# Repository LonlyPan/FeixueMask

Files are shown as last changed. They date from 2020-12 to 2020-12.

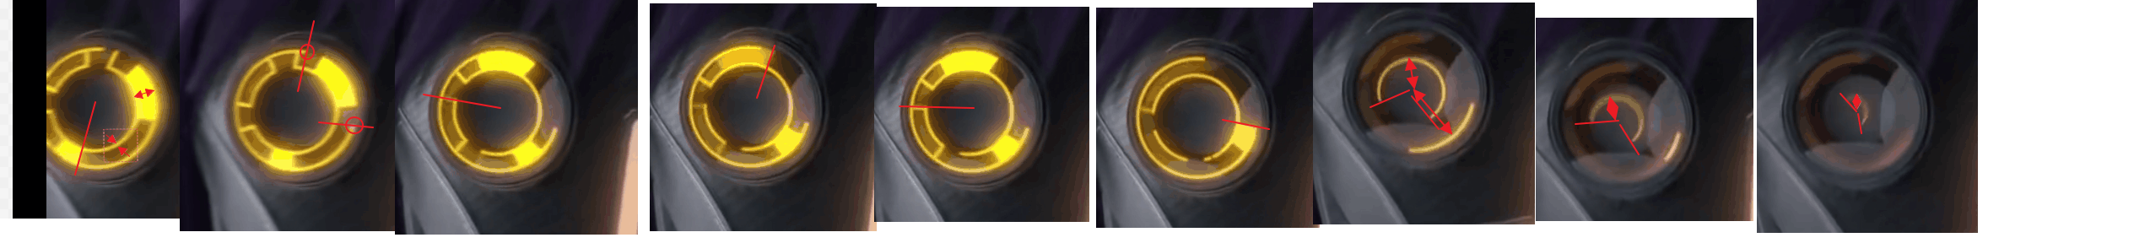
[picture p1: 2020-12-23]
04_others/飞雪显示界面/po57pm6ot55y8552bLeinkuW6pi5wbmc=.png

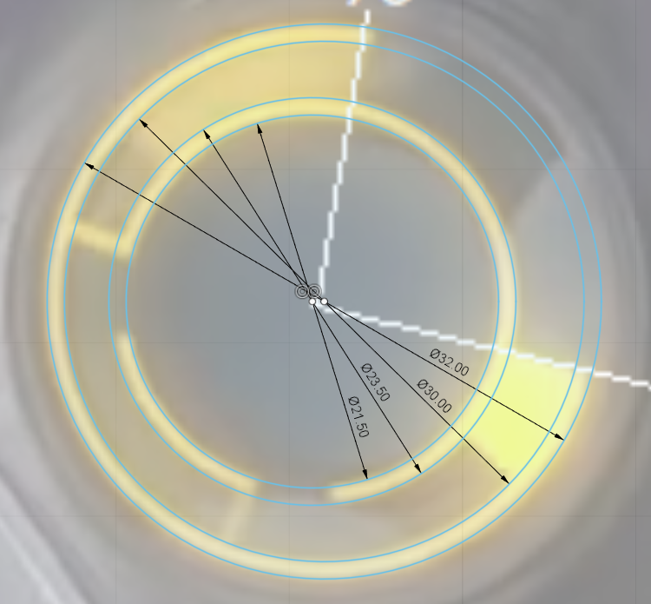
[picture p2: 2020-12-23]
04_others/飞雪显示界面/飞雪眼睛-线条宽度.png

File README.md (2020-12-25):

# 飞雪面具控制板源码




- **[English](/README_EN.md)**

飞雪面具控制板是[飞雪面具](https://www.bilibili.com/video/BV1Dy4y1i72c)的配套产品。

enter description here

## 如何找到文件

### 00_Priority README
该目录下存放了该控制板项目的全部**技术文档**，对该项目的程序源码、PCB设计都有详细说明，请首先阅读。
>文档目前尚未编写完成
>
### 01_Firmware
该目录下存放了 **软件/程序** 相关的全部源文件

### 02_Electronics
该目录下存放了 **电路/PCB** 相关的全部源文件

### 04_others
即不属于 软件/程序 也不属于 电路/PCB，但和本项目相关的其它文件

###  README.txt
每个文件夹下都有该文档，请**首先阅读**。这包含有其所处文件夹的阅读索引及一些重要说明。

## FeixueMask 1.0
FeixueMask 1.0 是该固件的初始版本，已经经过测试，可正常使用。

在[发布页面](https://github.com/LonlyPan/FeixueMask/releases)下载早期版本的FeixueMask固件。
>目前还未发布任何历史版本

## 支持

为了获得最佳的配置和故障排除帮助，请使用以下资源：
- 哔哩哔哩：[猩造](https://space.bilibili.com/16614468/)  
- 聊天催更Q群：779627778

## 许可协议

FeixueMask 是遵循 [GPL license](/LICENSE) 协议发行的，因为我们相信开放式开发。 GPL附带了权利和义务。 无论您使用 FeixueMask 固件作为开源产品还是封闭源产品的驱动程序，都必须保持 FeixueMask 开放，并且必须根据要求向最终用户提供兼容的 FeixueMask 源代码。 遵守 FeixueMask 许可证的最直接方法是在 Github 上制作 FeixueMask 的分支，执行您的修改，并将用户引导到您修改后的分支。

虽然我们不能禁止在具有封闭源代码或有专利保护的产品中使用此代码，但我们还是希望您选择其他固件，或者最好自己制作。

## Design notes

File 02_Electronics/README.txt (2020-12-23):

01_source ----------------------------------------- 存放软件源码和已迭代源码

02_tools ------------------------------------------- 程序编写相关软件及使用文档

03_documents ------------------------------------ PCB设计参考文档，含元器件手册

04_others ----------------------------------------- 其他文件

README.txt  -------------------------------------- 每个文件夹下都有该文件，为所处文件夹的阅读索引及必要说明

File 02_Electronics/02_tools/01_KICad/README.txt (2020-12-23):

library——为官方分装库文件及自己制作的封装/3D模型库
KiCad-doc_zh_CN_v0.4——官方文档教程中文版，较老

官方封装库文件是不含3D模型的，完整官方库文件下载：
https://kicad.github.io/footprints/

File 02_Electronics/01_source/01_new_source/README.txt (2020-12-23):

A1.0  2020-08-18
  原理图错误：
    1. Q1 引脚1、2颠倒（main、LED）
    2. RX接MCU引脚错误，应接PA10（main）
    3. 电容C2~5 值错误，应为 0.1uF（main）

V1.0  2020-08-21
   版本更新：
     1. 修复上一版设计错误（main、LED）
     2. LED灯板重新设计，三色灯改为单色灯（LED）
  版本错误：

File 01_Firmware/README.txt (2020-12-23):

01_source ----------------------------------------- 存放软件源码和已迭代源码

02_tools ------------------------------------------- 程序编写相关软件及使用文档

03_documents ------------------------------------ 软件设计参考文档

04_others ----------------------------------------- 其他文件

README.txt  -------------------------------------- 每个文件夹下都有该文件，为所处文件夹的阅读索引及必要说明

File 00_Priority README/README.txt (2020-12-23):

01-xx软件 ---- 存放技术文档软件安装包和使用文档。
02-source ---- 存放技术文档源文档（使用 xx软件 编写的文档默认格式）
03-others ---- 存放和技术文档相关的也很重要的文档资料

xxx.pdf为技术文档

技术文档及其他文档都是基于软件 "小书匠" 编写，该软件的免费版可正常使用所有的编辑功能，但无法导出一些特定格式且导出有水印。

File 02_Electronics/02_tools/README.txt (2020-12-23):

软件文件夹，含有软件安装包及相关安装、使用说明等。

软件可能不支持中文路径，需单独保存到全英文路径在运行

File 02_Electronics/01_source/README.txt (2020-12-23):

01_new_source -------------------------------- 存放最新源码（该目录仅存放一个最新版本）
    |________ Vx.x.x  --------------------  最新版本号
	     |________ 源码名1
	     |________ 源码名2  --------------------  有的工程可能会有同时多个源码

02_old_source --------------------------------- 存放已迭代源码
    |________ Vx.x.x  --------------------  旧版本号
	     |________ 源码名1
	     |________ 源码名2
    |________ Vx.x.x  --------------------  旧版本号
	 ......

有的编程软件可能不支持中文路径，需单独保存到全英文路径在运行

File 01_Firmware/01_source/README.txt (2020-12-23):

01_new_source -------------------------------- 存放最新源码
    |________ Vx.x.x  --------------------  最新版本号（该文件仅存放一个最新版本）
	     |________ 源码名1
	     |________ 源码名2  --------------------  有的工程可能会有同时多个源码

02_old_source --------------------------------- 存放已迭代源码
    |________ Vx.x.x  --------------------  旧版本号
	     |________ 源码名1
	     |________ 源码名2
    |________ Vx.x.x  --------------------  旧版本号
	 ......

有的编程软件可能不支持中文路径，需单独保存到全英文路径在运行

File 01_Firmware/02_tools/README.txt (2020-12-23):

含有各个编程相关软件的安装包及相关安装、使用说明等。

软件可能不支持中文路径，需单独保存到全英文路径在运行

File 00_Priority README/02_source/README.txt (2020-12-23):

该文件夹下存放技术文档的源文档（使用 xx软件 编写的文档默认格式）

如果想要编辑该目录下的文件，请先阅读 “如何编辑技术文档源文件pdf文件”

如果想要阅读该目录下的文件，请转至该文件夹的上级文件夹，阅读其内与该文件夹同名的 .pdf 文件（.pdf为该目录下 .md文档 的导出文件）。

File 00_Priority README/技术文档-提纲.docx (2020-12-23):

1、研发人员相关信息：名字，职位，时间，等

2、所负责的研发工作的主要内容简介：项目名、子项目名、功能、目的、关键技术、难点、待解决的问题，等

3、技术方案：原理、系统框图及解释，等

4、具体技术细节：

（1）开发过程记录；

（2）不同职位对应的工作：

*电子工程师要做的：电子零件清单及型号、Datasheet，原理图、PCB图、封装等电路设计文档，配合原理图进行文字性的原理解释；

*软件工程师要做的：包含注释的程序源代码、对程序的修改说明（例如对开源程序的修改）、程序的整体框图/模块图、主要函数之间的调用关系、开发环境及其建立方法；

*机械工程师要做的：机械零件清单及三维设计模型、爆炸图、组装好的三维模型，装配说明；

*嵌入式开发人员要做的：涉及电子工程师和软件工程师两方面的工作，参考上面的电子和软件方面的要求，把电路和程序一起归档；

*材料工程师要做的：材料名称（包括中文名、英文名、化学名、分子式等），配方（包括每种组分的中文名、英文名、化学名、分子式、重量比例或体积比、颗粒物的粒径等），组分调配方法（混合方法、步骤及反应时长、温度、压力、酸碱度等工艺参数），组分之间的相互作用，材料的表征，不同组分的采购渠道/供应商，等；

*算法工程师要做的：算法的数学模型及其推导过程，数学模型的文字化详细阐述，算法的计算机程序实现过程，程序源码及其注释，编译环境的建立及调试，模块化封装及其API接口，调用方法及所需传递的参数，与其它图形化界面程序的整合方法，等；

（3）测试/调试方法或详细说明。

5、待解决的问题：问题列表，对策（如果有），建议

6、附录：附属文件的列表及简要说明，供应商列表（例如主要电子零件的销售方、PCB板的生产商、机械零件的销售方、机械加工的供应方、材料的销售方）、程序的库文件列表、相关资源的网络链接，此部分内容可以用Excel文件单独详细列出

（解释：研发过程是在公司框架内实施的，研发所产生的技术、文档都属于公司资产；技术归档是公司研发管理的必须程序；技术文档将为公司管理，尤其是为后续研发工作提供基础）

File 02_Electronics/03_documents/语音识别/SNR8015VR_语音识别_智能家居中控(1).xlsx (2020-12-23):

智能家居中控 |  |  |  | 指令定制建议 | 模块输出串口指令
序號 | 唤醒词 | 反馈音 | 备注 |  | 串口指令 | 1 | 2 | 3 | 4 | 备注
指令1 | 小爱同学 | 有什么可以帮您 | 随机 播放一句 | 唤醒词建议3～5字，采用ABCD形式，例如"小明你好" |  | 0xF4 | 0x06 | 0x01 | 0xFF | 波特率 9600bps
 | 小智你好 | 你好呀 |  |  | 说明 | 第三字节对应指令ID
 | 小美你好 | 我在呢
 | 智能管家
 | 功能组1 | 反馈音 | 备注
指令2 | 打开灯光 | 灯已打开 | IO1高电平 | 功能指令建议3~5字，不同指令之间须有两个字以上差异，识别效果好，不易混淆，尽量避开相近发音词，例如"往后往后"和"往右往右" | 识别指令1 | 0xF4 | 0x06 | 0x01 | 0xFF
指令3 | 关闭灯光 | 灯已关闭 | IO1低电平 |  | 识别指令2 | 0xF4 | 0x06 | 0x02 | 0xFF
指令4 | 灯光调亮 | 已调亮 |  |  | 识别指令3 | 0xF4 | 0x06 | 0x03 | 0xFF
指令5 | 灯光调暗 | 已调暗 |  |  | 识别指令4 | 0xF4 | 0x06 | 0x04 | 0xFF
指令6 | 最大亮度 | 已最亮 |  |  | 识别指令5 | 0xF4 | 0x06 | 0x05 | 0xFF
指令7 | 最小亮度 | 已最暗 |  |  | 识别指令6 | 0xF4 | 0x06 | 0x06 | 0xFF
指令8 | 打开风扇 | 风扇已打开 | IO2高电平 |  | 识别指令7 | 0xF4 | 0x06 | 0x07 | 0xFF
指令9 | 关闭风扇 | 风扇已关闭 | IO2低电平 |  | 识别指令8 | 0xF4 | 0x06 | 0x08 | 0xFF
指令10 | 风速一档 | 风速一挡 |  |  | 识别指令9 | 0xF4 | 0x06 | 0x09 | 0xFF
指令11 | 风速二档 | 风速二挡
指令12 | 风速三档 | 风速三挡 |  |  | 模块输入串口指令
指令13 | 风速四档 | 风速四挡 |  |  | 串口指令 | 1 | 2 | 3 | 4 | 备注
指令14 | 风速五档 | 风速五挡 |  |  |  | 0xF4 | 0x06 | 0x01 | 0xFF | 波特率 9600bps
指令15 | 风速最高 | 风速已最高 |  |  | 说明 | 第三字节对应指令ID
指令16 | 风速最低 | 风速已最低
指令17 | 风扇摇头 | 已开始摇头
指令18 | 停止摇头 | 已停止摇头 |  |  | 语音播报1 | 0xF4 | 0x06 | 0x01 | 0xFF
指令19 | 打开空调 | 空调已打开 | IO3高电平 |  | 语音播报2 | 0xF4 | 0x06 | 0x02 | 0xFF
指令20 | 关闭空调 | 空调已关闭 | IO3低电平 |  | 语音播报3 | 0xF4 | 0x06 | 0x03 | 0xFF
指令21 | 二十三度 | 二十三度 |  |  | 语音播报4 | 0xF4 | 0x06 | 0x04 | 0xFF
指令22 | 二十五度 | 二十五度 |  |  | 语音播报5 | 0xF4 | 0x06 | 0x05 | 0xFF
指令23 | 二十七度 | 二十七度 |  |  | 语音播报6 | 0xF4 | 0x06 | 0x06 | 0xFF
指令24 | 二十九度 | 二十九度 |  |  | 语音播报7 | 0xF4 | 0x06 | 0x07 | 0xFF
指令25 | 上下扫风 | 上下扫风 |  |  | 语音播报8 | 0xF4 | 0x06 | 0x08 | 0xFF
指令26 | 左右扫风 | 左右扫风 |  |  | 语音播报9 | 0xF4 | 0x06 | 0x09 | 0xFF
指令27 | 打开窗帘 | 窗帘已打开 | IO4高电平
指令28 | 关闭窗帘 | 窗帘已关闭 | IO4低电平 |  | 串口指令设定音量
指令29 | 打开窗纱 | 窗纱已打开 | IO5高电平 |  | 串口指令 | 1 | 2 | 3 | 4 | 备注
指令30 | 关闭窗纱 | 窗纱已关闭 | IO5低电平 |  |  | 0xF4 | 0x08 | 0x01 | 0xFF | 波特率 9600bps
指令31 | 播放音乐 | 开始播放 |  |  | 说明 | 0x01：最大音量
指令32 | 停止播放 | 停止播放 |  |  |  | 0x02：中等音量
指令33 | 上一曲 | 上一曲 |  |  |  | 0x03：最小音量
指令34 | 下一曲 | 下一曲 |  |  |  | 0x04：音量增加
指令35 | 增大音量 | 音量已增大 |  |  |  | 0x05：音量减小
指令36 | 减小音量 | 音量已减小 |  |  |  | 0x06：开启静音
指令37 | 最大音量 | 最大音量 |  |  |  | 0x07：取消静音
指令38 | 中等音量 | 中等音量
指令39 | 最小音量 | 最小音量 |  |  | 串口指令设定唤醒超时状态
 | 超时 | 反馈音 | 备注 |  | 串口指令 | 1 | 2 | 3 | 4 | 备注
 |  | 我先退下了 | 15秒钟无指令识别自动超时 |  | 说明 | 0xF4 | 0x0A | 0x01 | 0xFF | 波特率 9600bps
 |  |  |  |  |  | 0x01：语音识别唤醒
 | 语音播报 | 播报音 | 备注 |  |  | 0x02：语音识别超时
播报1-18 |  | 指令1-18的反馈音 | 由从机 控制播放
开机播报 |  | 我是语音识别助手小智，你可以对我说小智你好，唤醒我
可自定义词条、反馈音，联系客 服为您量身定制定制模块哦！

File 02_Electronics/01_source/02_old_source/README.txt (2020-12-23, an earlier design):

文件夹命名规则：xx-文件夹名_Vx.x

有的编程软件可能不支持中文路径，需单独保存到全英文路径在运行

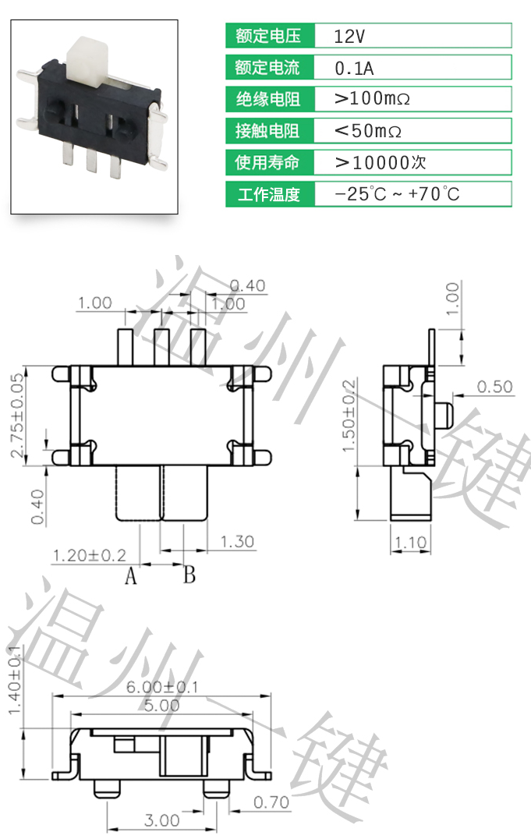
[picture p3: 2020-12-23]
02_Electronics/03_documents/开关规格.png

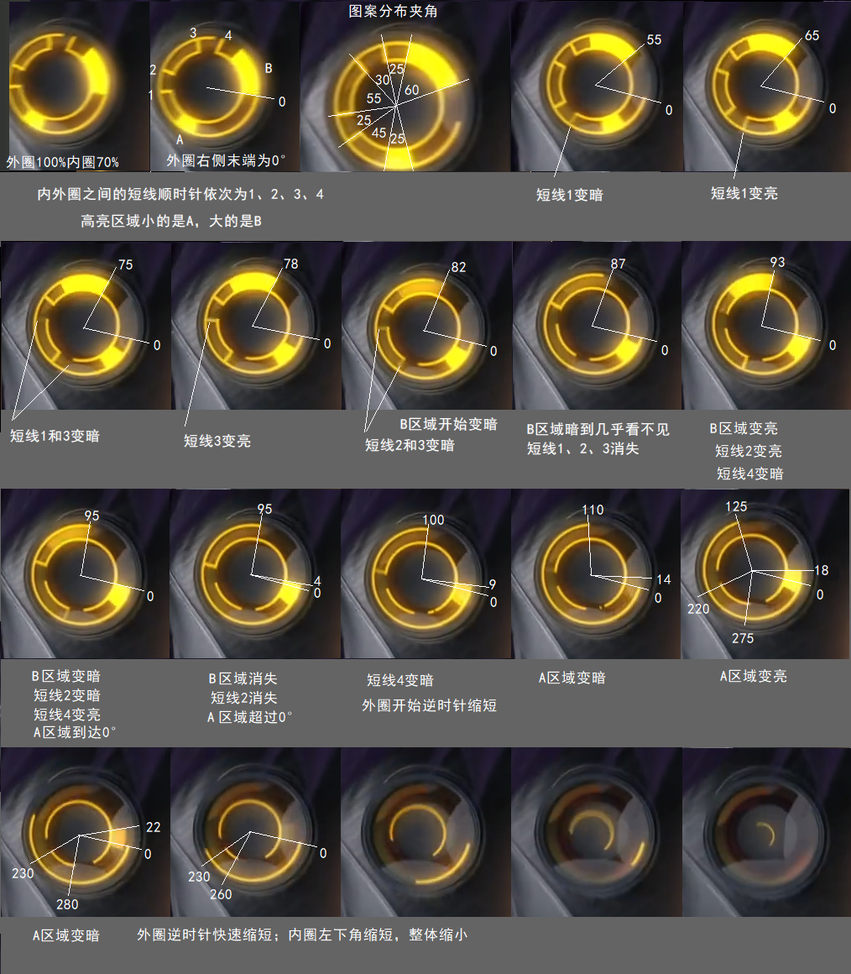
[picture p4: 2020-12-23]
04_others/飞雪显示界面/飞雪眼睛图案.png

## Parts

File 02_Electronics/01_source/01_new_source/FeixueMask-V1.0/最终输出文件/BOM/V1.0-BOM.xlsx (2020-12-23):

Feixue-main-BOM
Reference | Quantity | Value | Footprint | Datasheet/备注 | 采购建议
C1 | 1 | 2.2uF | C_0603_1608Metric | ±10% 6.3V/10V/16V | https://item.szlcsc.com/1959.html
C16 C15 | 2 | 12pF ±1% 6.3V/10V/16V | C_0603_1608Metric | ±1% 6.3V/10V/16V | https://item.szlcsc.com/193883.html
C18 | 1 | 100pF ±1/5% 6.3V/10V/16V | C_0603_1608Metric | ±5/10% 6.3V/10V/16V | https://item.szlcsc.com/15333.html
C6 C7 C2 C3 C4 C5 C12 C20 | 8 | 1uF | C_0603_1608Metric | ±5/10% 6.3V/10V/16V | https://item.szlcsc.com/1944.html
C8 C10 C17 C13 C21 C23 | 6 | 0.1uF | C_0603_1608Metric | ±5/10% 6.3V/10V/16V | https://item.szlcsc.com/1943.html
C9 C14 C19 C22 C11 | 5 | 4.7uF | C_0603_1608Metric | ±5/10% 6.3V/10V/16V | https://item.szlcsc.com/2057.html
J1 | 1 | TFT-1.28寸 | FPC-0.7-Handsoldering-1.28-TFT | 1.28寸圆形 SPI通信 TFT显示屏（非触摸） | https://item.taobao.com/item.htm?spm=a1z09.2.0.0.60992e8dttdmLE&id=607100059457&_u=mpkffgd9630
J2 | 1 | battery | Common_Connect_1.52x2.6_Handsoldering | 电池接口、由于空间狭小，小电池续航较短，更具需求也可使用引线引出 | https://item.taobao.com/item.htm?spm=a1z09.2.0.0.60992e8dttdmLE&id=596628957245&_u=mpkffgd0636
J3 | 1 | SWD | Con-1x4-P1.25mm | 程序下载接口，需要搭配 探针4px1.25+ST-Link 使用 | https://detail.tmall.com/item.htm?id=601843169152&ns=1&abbucket=19&skuId=4346981708084
J4 | 1 | LED | FPC-0.7x5-Handsoldering | LED灯板与主板FPC接口 0.7间距x5p 60mm长 | https://item.taobao.com/item.htm?spm=a1z09.2.0.0.60992e8dttdmLE&id=577237256700&_u=mpkffgdbad0
MK1 | 1 | Microphone | Condenser-Microphone-4012 | 麦克风 4.0*1.2mm 1.1V-10V 灵敏度-42dB，注意尺寸 | https://item.szlcsc.com/233557.html
Q1 | 1 | SS8050 | SOT-23 | NPN Ic=1.5A 300mW 注意引脚顺序 | https://item.szlcsc.com/2507.html
R1 | 1 | 100K | R_0603_1608Metric | ±1% 0.1W_1/16W | https://item.szlcsc.com/26546.html
R2 | 1 | 1K | R_0603_1608Metric | ±1% 0.1W_1/16W | https://item.szlcsc.com/21904.html
R3 | 1 | 10K | R_0603_1608Metric | ±1% 0.1W_1/16W | https://item.szlcsc.com/99429.html
R4 | 1 | 10R | R_0603_1608Metric | ±1% 0.1W_1/16W | https://item.szlcsc.com/23586.html
R5 | 1 | 82K | R_0603_1608Metric | ±1% 0.1W_1/16W | https://item.szlcsc.com/23981.html
R6 | 1 | 2.2K | R_0603_1608Metric | ±1% 0.1W_1/16W | https://item.szlcsc.com/4597.html
R7 R8 | 2 | 220R | R_0603_1608Metric | ±1% 0.1W_1/16W | https://item.szlcsc.com/23689.html
SW1 | 1 | SW_SPDT | MSKT-12C00-switch-smd | 电源开关 | https://item.taobao.com/item.htm?spm=a1z09.2.0.0.60992e8dttdmLE&id=537132709077&_u=mpkffgd92dc
U1 | 1 | STM32F401CCUx | QFN-48-1EP_7x7mm_P0.5mm_EP5.6x5.6mm | 主控MCU单片机 | https://item.szlcsc.com/81004.html
U2 | 1 | XC6206 | SOT-23 | 3.3V稳压芯片 | https://item.szlcsc.com/324036.html
U3 | 1 | SNR8015VR | QSOP-24_3.9x8.7mm_P0.635mm | 语音芯片（只要芯片） | https://item.taobao.com/item.htm?spm=a1z09.2.0.0.60992e8dttdmLE&id=625406464368&_u=mpkffgd08a0
Y1 | 1 | 12MHz/12pF/10ppm | Crystal_SMD_2520-4Pin_2.5x2.0mm | 晶振 | https://item.szlcsc.com/684571.html
Feixue-LED-BOM
Reference | Quantity | Value | Footprint | Datasheet | 采购建议
D1 D2 D3 | 3 | LED | LED_0805_2012Metric | LED灯从购买的灯条拆卸而来，3V 72灯 1米 黄色 | https://item.taobao.com/item.htm?spm=a1z09.2.0.0.38e42e8dOqAm56&id=610193738983&_u=l1tpseqd237d
Q1 | 1 | SS8050 | SOT-23 | NPN Ic=1.5A 300mW 注意引脚顺序 | https://item.szlcsc.com/2507.html
R11 | 1 | 1K | R_0603_1608Metric | ±1% 0.1W_1/16W | https://item.szlcsc.com/21904.html
R1 R2 R3 | 3 | 470R | R_0603_1608Metric | ±1% 0.1W_1/16W | https://item.szlcsc.com/23906.html

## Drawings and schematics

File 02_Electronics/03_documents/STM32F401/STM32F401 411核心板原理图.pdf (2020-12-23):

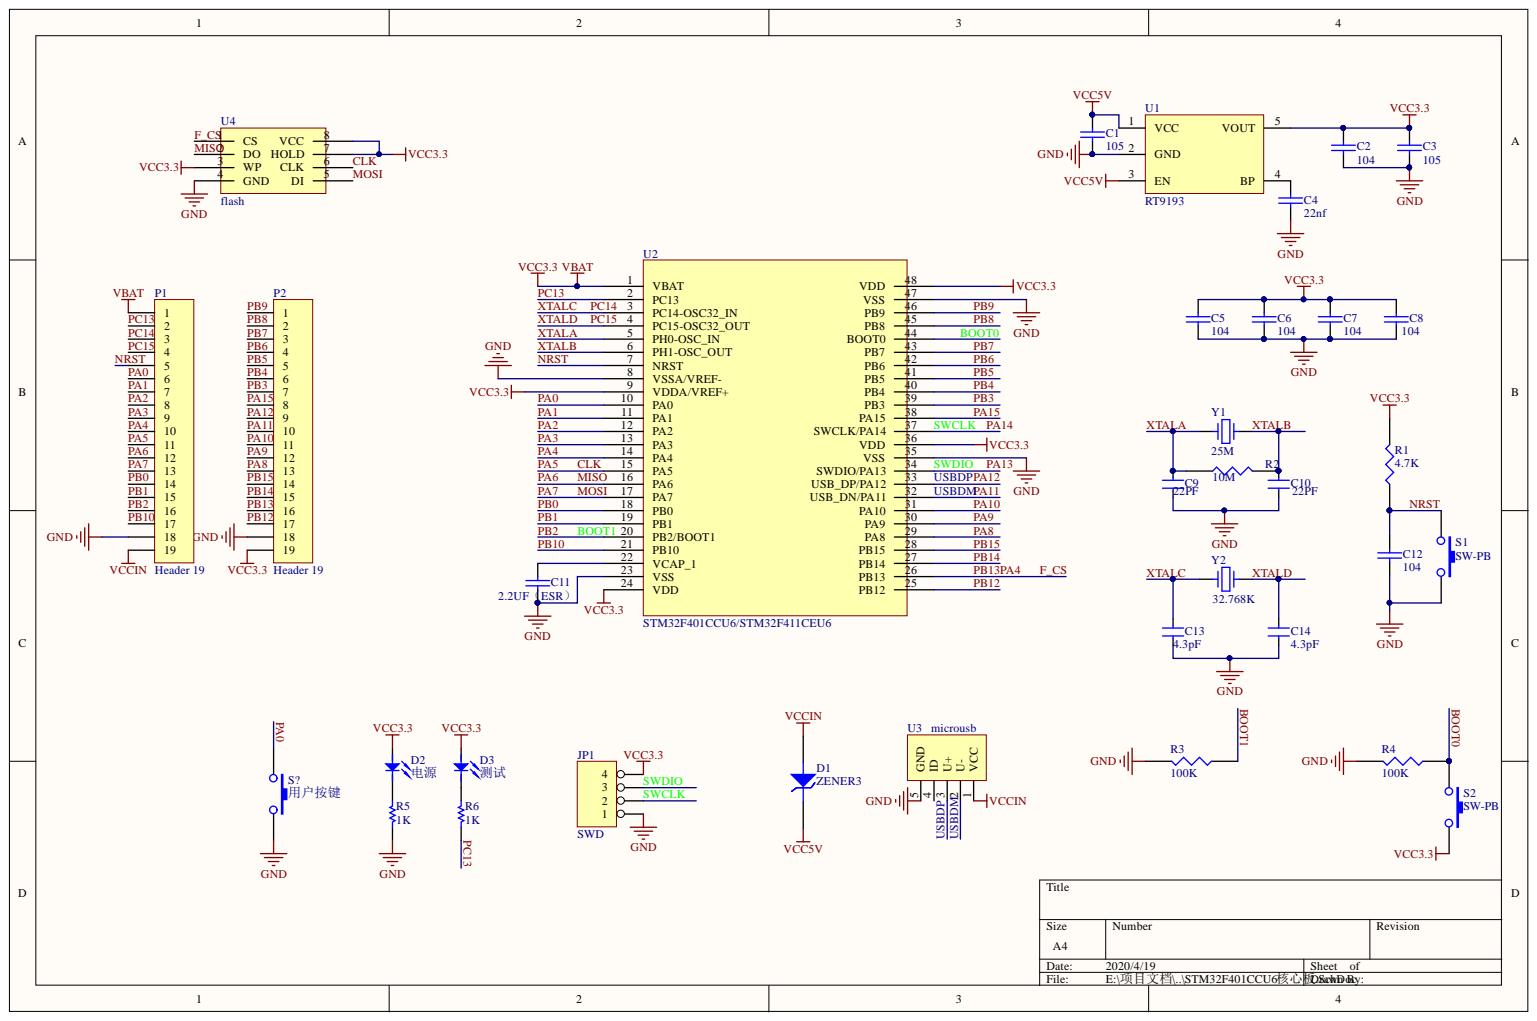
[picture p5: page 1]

VCC 1 U- 2 U+ 3 ID 4 GND 5 U3 microusb

6核心板D.Sch rawDn By oc
1CCU

Comment | Description | Designator | Footprint | LibRef | Quantity
105 | Capacitor | C1, C3 | 0603C | CAP | 2
104 | Capacitor, [NoValue], [NoValue], [NoValue], [NoValue], [NoValue] | C2, C5, C6, C7, C8, C12 | 0603C | CAP | 6
22nf | Capacitor | C4 | 0603C | CAP | 1
22PF | SMD-CAP | C9, C10 | 0603C | CAP-0.1UF | 2
2.2UF ESR （ ） | Capacitor | C11 | 0603C | CAP | 1
4.3pF | SMD-CAP | C13, C14 | 0603C | CAP-0.1UF | 2
ZENER3 | Zener Diode | D1 | 0805D | ZENER3 | 1
电源 | | D2 | 0603D | LED | 1
测试 | | D3 | 0603D | LED | 1
SWD | 4 Pin Header | JP1 | HDR1X4 | 4 HEADER | 1
Header 19 | Header, 19-Pin | P1, P2 | HDR1X19 | Header 19 | 2
4.7K | | R1 | 0603B | RES1 | 1
10M | | R2 | 0603B | RES1 | 1
100K | | R3, R4 | 0603B | RES1 | 2
1K | Resistor | R5, R6 | 0603B | Res1 | 2
SW-PB | | S1, S2 | 贴片按键 4x3 | SW-PB | 2
用户按键 | | S? | 贴片按键 4x3 | SW-PB | 1
RT9193 | | U1 | SOT23-5 | RT9193 | 1
STM32F401CCU6/STM3 2F411CEU6 | | U2 | QFN48 | STM32F401CCU6 | 1
microusb | | U3 | MICRO-USB | microusb | 1
flash | | U4 | SOP127P800X265-8N | flash | 1
25M | 晶振 | Y1 | 3225 - duplicate | XT | 1
32.768K | 晶振 | Y2 | 晶振 32.768K | XT | 1

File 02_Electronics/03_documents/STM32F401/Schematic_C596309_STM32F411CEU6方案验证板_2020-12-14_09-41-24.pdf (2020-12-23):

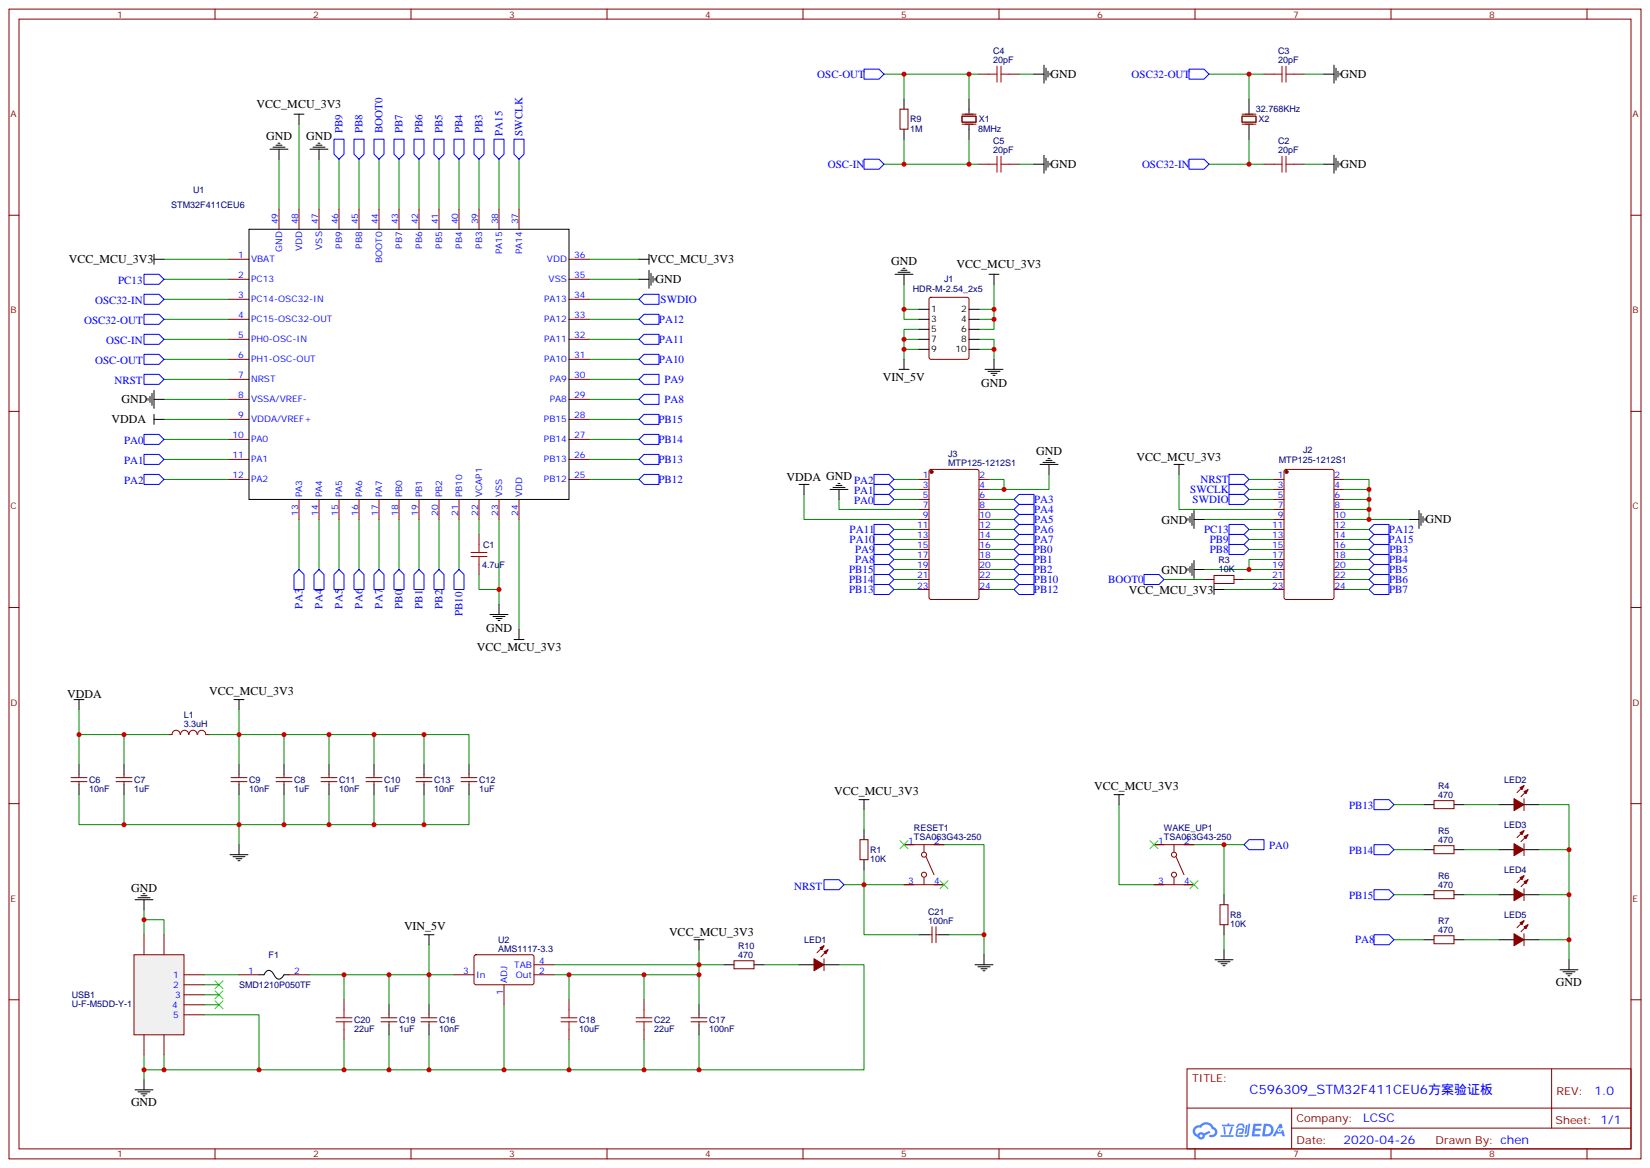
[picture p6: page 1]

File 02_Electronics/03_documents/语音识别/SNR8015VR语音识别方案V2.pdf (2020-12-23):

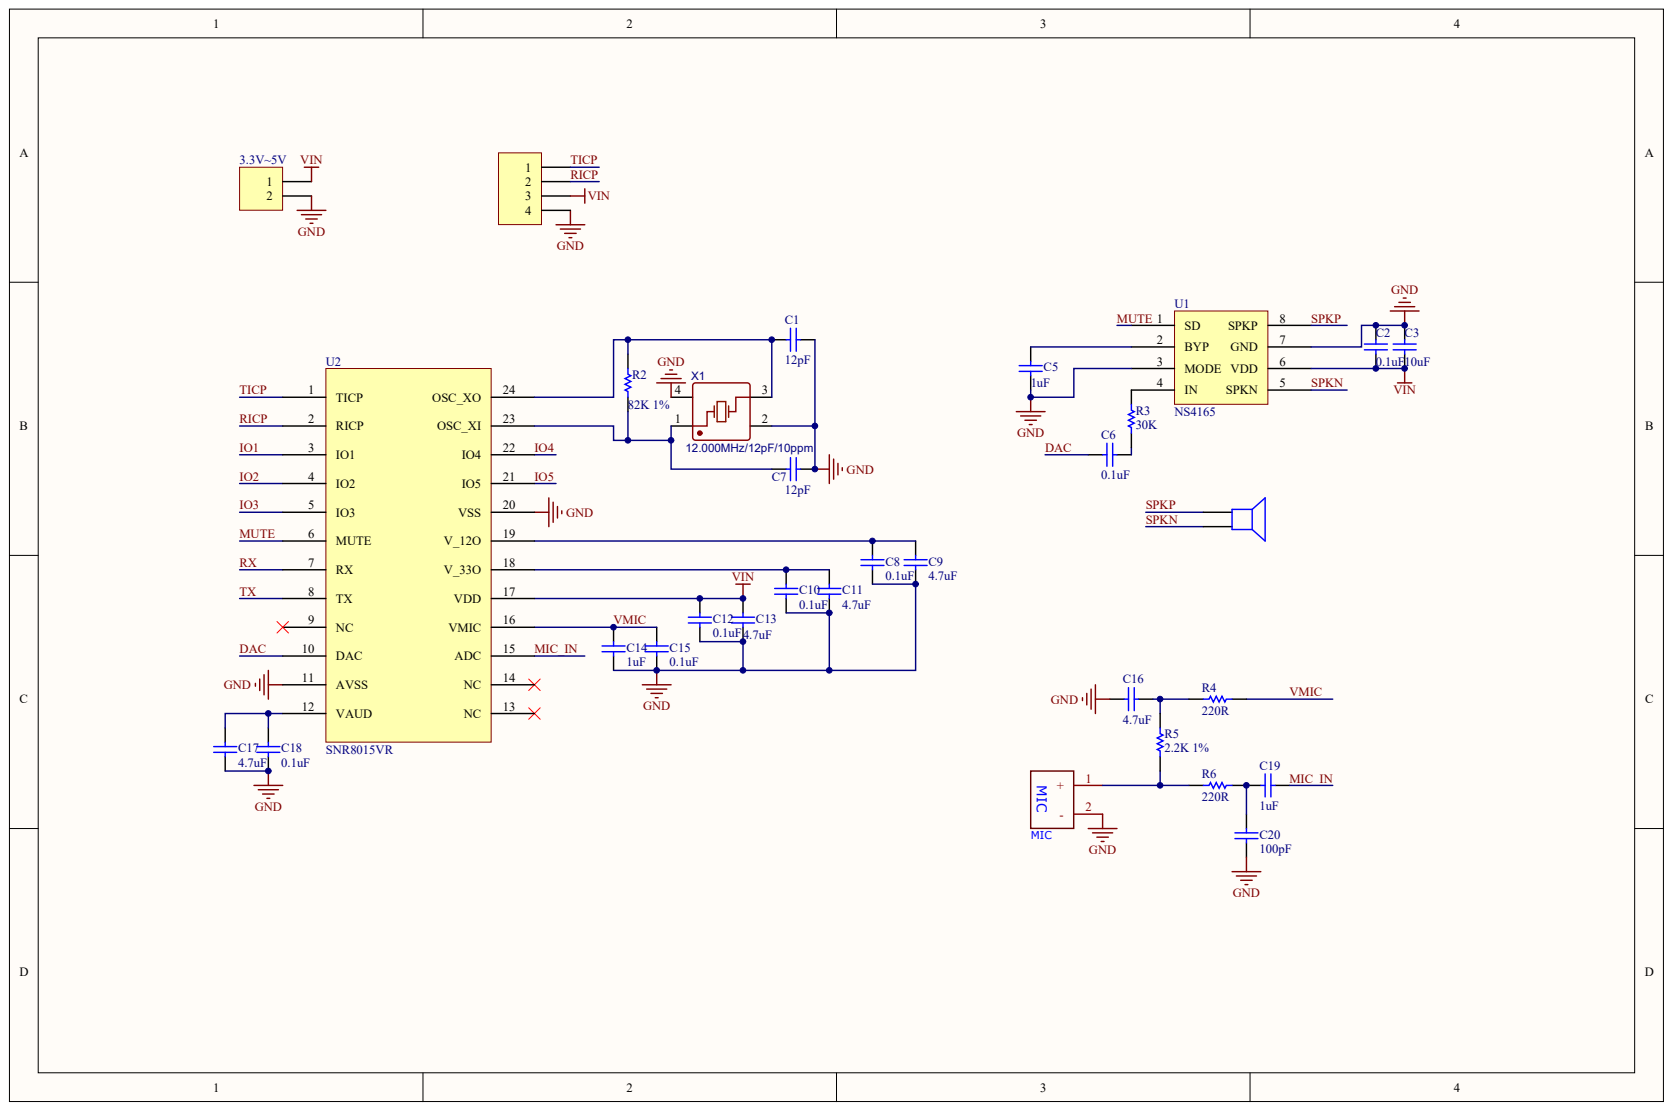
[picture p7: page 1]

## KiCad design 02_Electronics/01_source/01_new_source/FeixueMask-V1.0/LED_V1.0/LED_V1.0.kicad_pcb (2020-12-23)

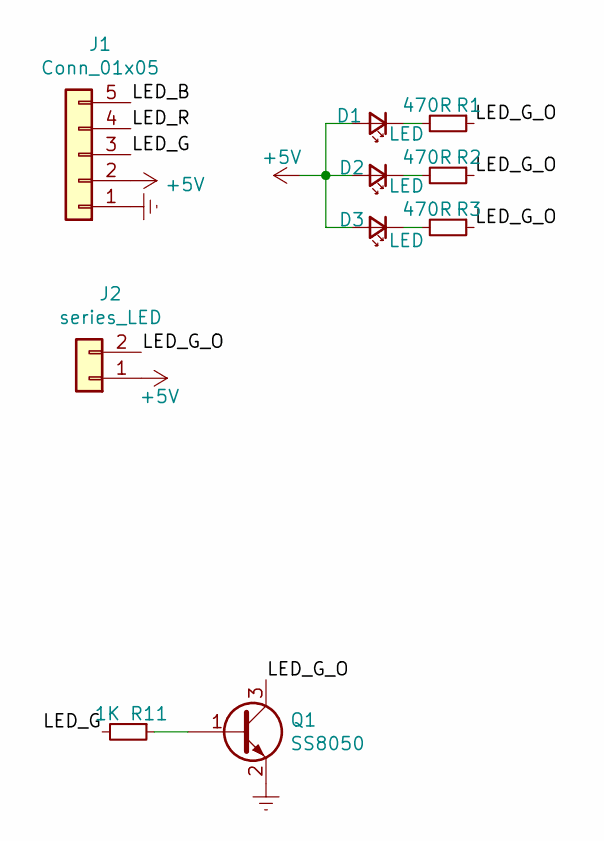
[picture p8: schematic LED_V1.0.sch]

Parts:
D1, D2, D3: LED; LED_0805_2012Metric
J1: Conn_01x05; FPC-0.7x5-Handsoldering
J2: series_LED; Pad-2.2mm_1.5x1.5
Q1: SS8050; SOT-23
R1, R2, R3: 470R; R_0603_1608Metric
R11: 1K; R_0603_1608Metric

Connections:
+5V: D1.2 (A), D2.2 (A), D3.2 (A), J1.2, J2.1
/LED_B: J1.5
/LED_G: J1.3, R11.2
/LED_G_O: J2.2, Q1.3 (C), R1.1, R2.1, R3.1
/LED_R: J1.4
Earth: J1.1, Q1.2 (E)
unnamed: D1.1 (K), R1.2
unnamed: D2.1 (K), R2.2
unnamed: D3.1 (K), R3.2
unnamed: Q1.1 (B), R11.1

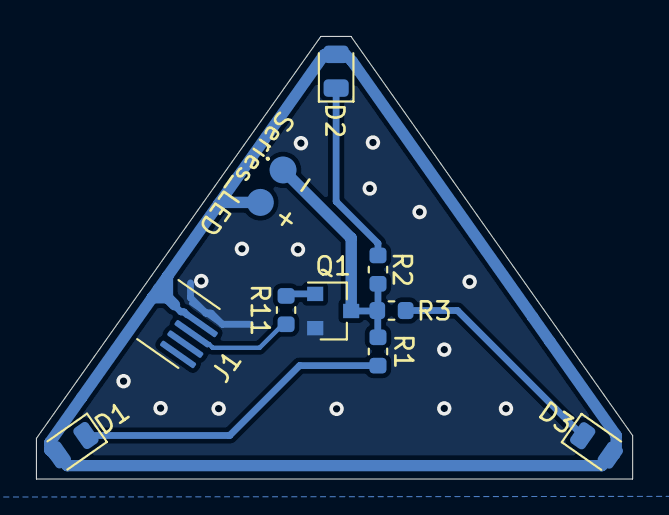
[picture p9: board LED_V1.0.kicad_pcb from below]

Board: 2 copper layers, 33.1 x 24.6 mm, 10 parts (10 on the bottom side), 8 nets.

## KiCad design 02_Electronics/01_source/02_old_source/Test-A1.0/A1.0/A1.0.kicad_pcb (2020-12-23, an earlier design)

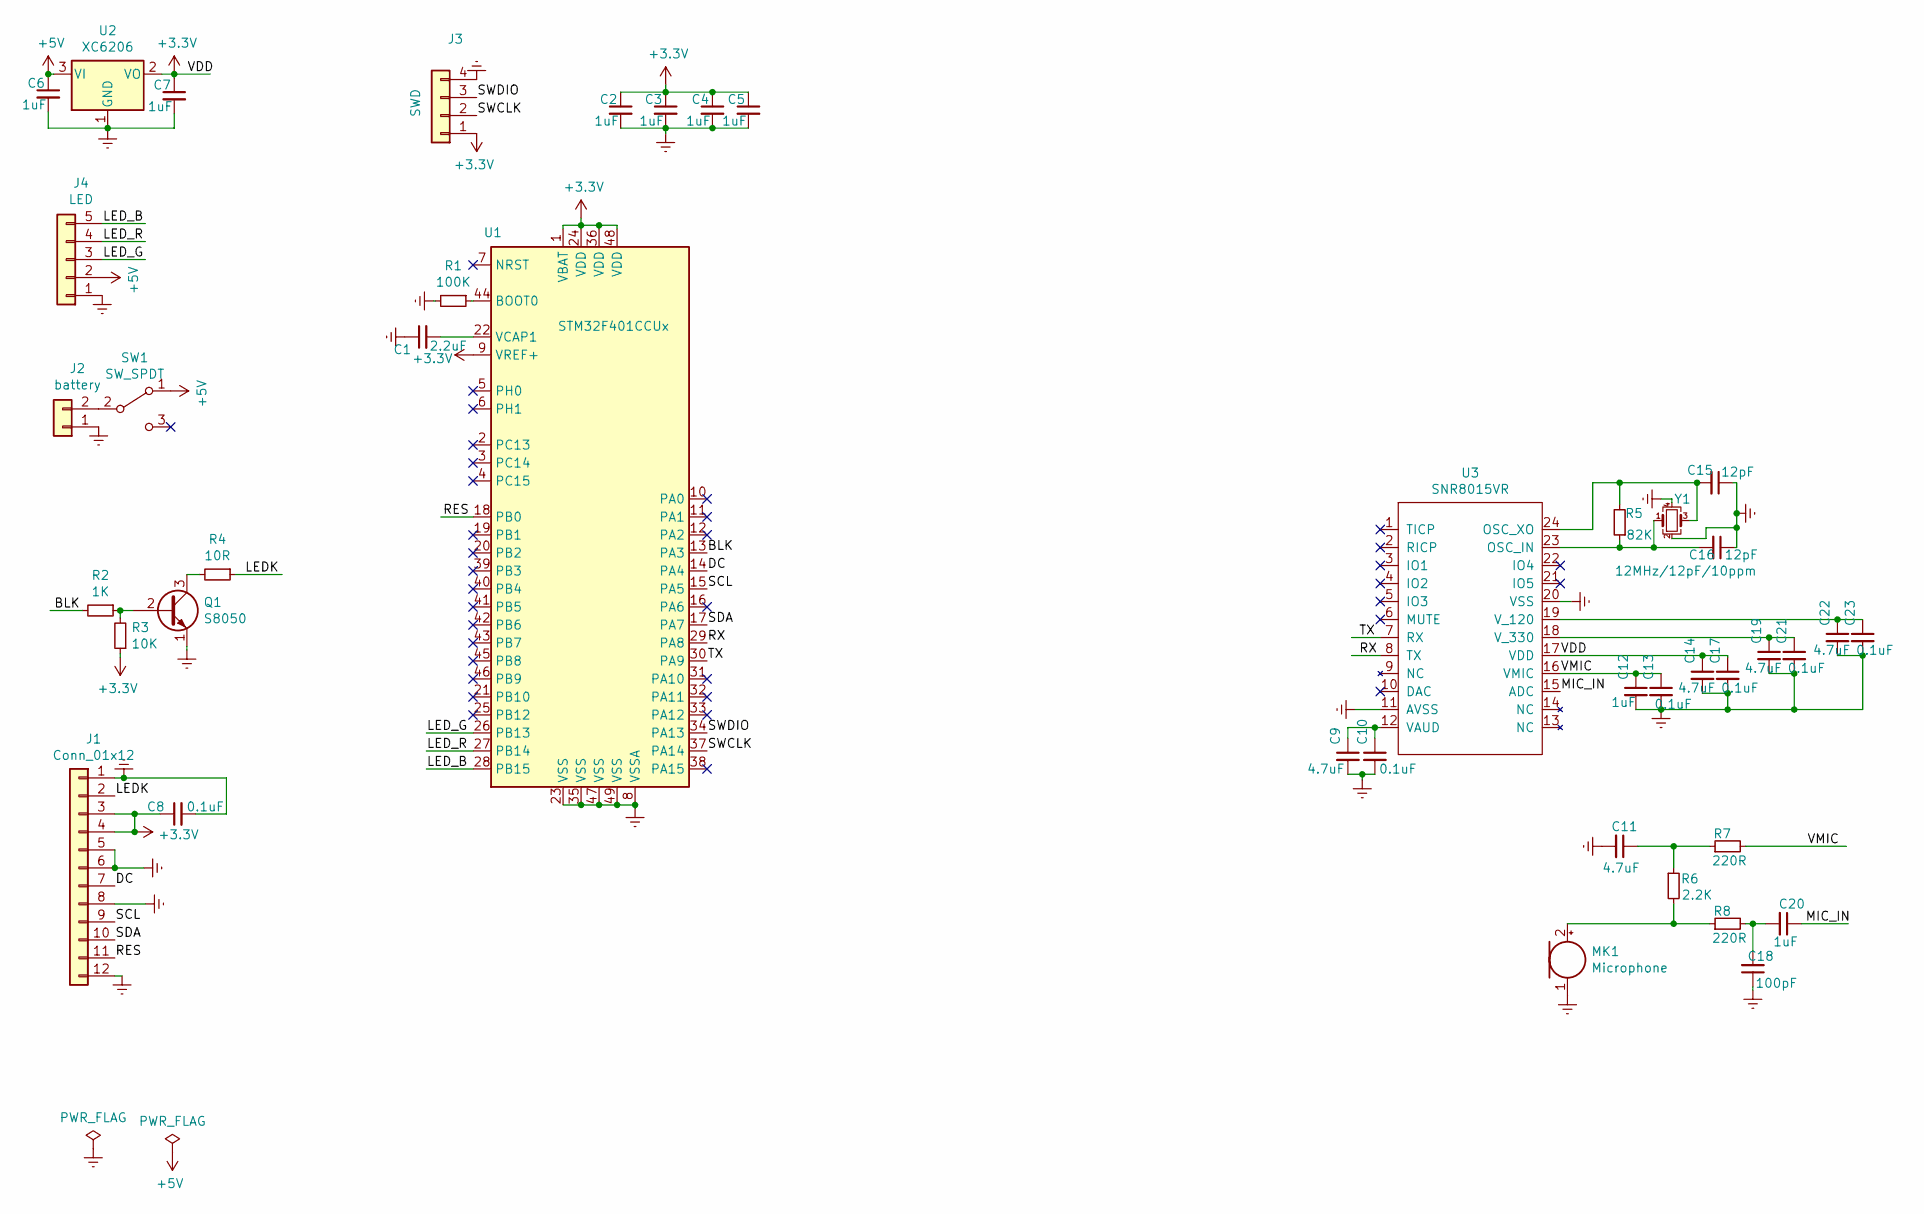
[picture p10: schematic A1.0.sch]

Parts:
C1: 2.2uF; C_0603_1608Metric
C2, C3, C4, C5, C6, C7, C12, C20: 1uF; C_0603_1608Metric
C8, C10, C13, C17, C21, C23: 0.1uF; C_0603_1608Metric
C9, C11, C14, C19, C22: 4.7uF; C_0603_1608Metric
C15, C16: 12pF; C_0603_1608Metric
C18: 100pF; C_0603_1608Metric
J1: Conn_01x12; FPC-0.7-Handsoldering-1.28-TFT
J2: battery; Speaker
J3: SWD; Con-1x4-P1.25mm
J4: LED; FPC-0.7x5-Handsoldering
MK1: Microphone; Condenser-Microphone-4012
Q1: S8050; SOT-23
R1: 100K; R_0603_1608Metric
R2: 1K; R_0603_1608Metric
R3: 10K; R_0603_1608Metric
R4: 10R; R_0603_1608Metric
R5: 82K; R_0603_1608Metric
R6: 2.2K; R_0603_1608Metric
R7, R8: 220R; R_0603_1608Metric
SW1: SW_SPDT; MSKT-12C00-switch-smd
U1: STM32F401CCUx; QFN-48-1EP_7x7mm_P0.5mm_EP5.6x5.6mm
U2: XC6206; SOT-23
U3: SNR8015VR; QSOP-24_3.9x8.7mm_P0.635mm
Y1: 12MHz/12pF/10ppm; Crystal_SMD_2520-4Pin_2.5x2.0mm

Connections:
+3V3: C2.1, C3.1, C4.1, C5.1, C7.1, C8.1, C14.1, C17.1, J1.3, J1.4, J3.1, R3.1, U1.1 (VBAT), U1.9 (VREF+), U1.24 (VDD), U1.36 (VDD), U1.48 (VDD), U2.2 (VO), U3.17 (VDD)
+5V: C6.1, J4.2, SW1.1 (A), U2.3 (VI)
/BLK: R2.2, U1.13 (PA3)
/DC: J1.7, U1.14 (PA4)
/LEDK: J1.2, R4.1
/LED_B: J4.5, U1.28 (PB15)
/LED_G: J4.3, U1.26 (PB13)
/LED_R: J4.4, U1.27 (PB14)
/MIC_IN: C20.1, U3.15 (ADC)
/RES: J1.11, U1.18 (PB0)
/RX: U1.29 (PA8), U3.8 (TX)
/SCL: J1.9, U1.15 (PA5)
/SDA: J1.10, U1.17 (PA7)
/SWCLK: J3.2, U1.37 (PA14)
/SWDIO: J3.3, U1.34 (PA13)
/TX: U1.30 (PA9), U3.7 (RX)
/VMIC: C12.1, C13.1, R7.2, U3.16 (VMIC)
Earth: C1.1, C2.2, C3.2, C4.2, C5.2, C6.2, C7.2, C8.2, C9.2, C10.2, C11.2, C12.2, C13.2, C14.2, C15.1, C16.1, C17.2, C18.1, C19.2, C21.2, C22.2, C23.2, J1.1, J1.5, J1.6, J1.8, J1.12, J2.1, J3.4, J4.1, MK1.1 (-), Q1.1 (E), R1.2, U1.8 (VSSA), U1.23 (VSS), U1.35 (VSS), U1.47 (VSS), U1.49 (VSS), U2.1 (GND), U3.11 (AVSS), U3.20 (VSS), Y1.2, Y1.4
unnamed: C1.2, U1.22 (VCAP1)
unnamed: C9.1, C10.1, U3.12 (VAUD)
unnamed: C11.1, R6.1, R7.1
unnamed: C15.2, R5.2, U3.24 (OSC_XO), Y1.3
unnamed: C16.2, R5.1, U3.23 (OSC_IN), Y1.1
unnamed: C18.2, C20.2, R8.2
unnamed: C19.1, C21.1, U3.18 (V_330)
unnamed: C22.1, C23.1, U3.19 (V_120)
unnamed: J2.2, SW1.2 (B)
unnamed: MK1.2 (+), R6.2, R8.1
unnamed: Q1.2 (B), R2.1, R3.2
unnamed: Q1.3 (C), R4.2
unnamed: R1.1, U1.44 (BOOT0)

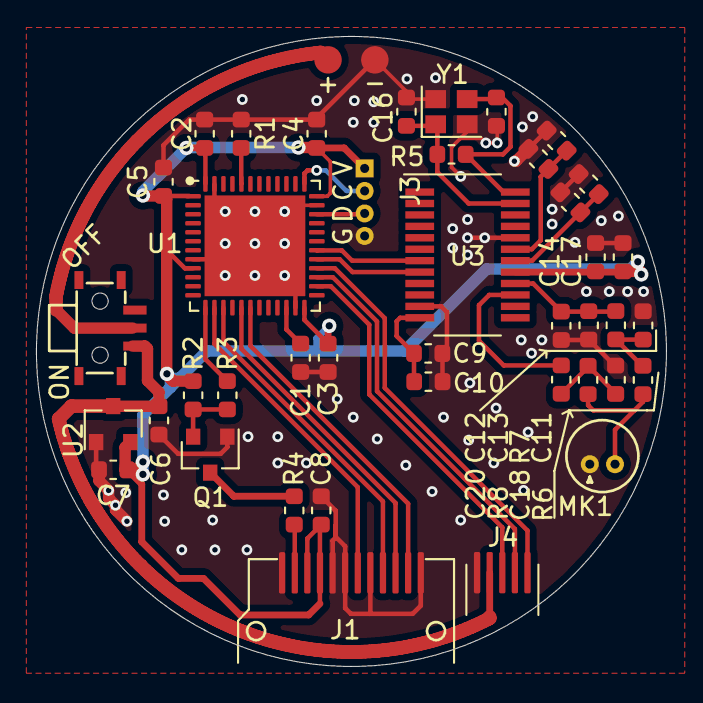
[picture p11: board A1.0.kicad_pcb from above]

Board: 2 copper layers, 35.0 x 35.0 mm, 42 parts (0 on the bottom side), 31 nets.

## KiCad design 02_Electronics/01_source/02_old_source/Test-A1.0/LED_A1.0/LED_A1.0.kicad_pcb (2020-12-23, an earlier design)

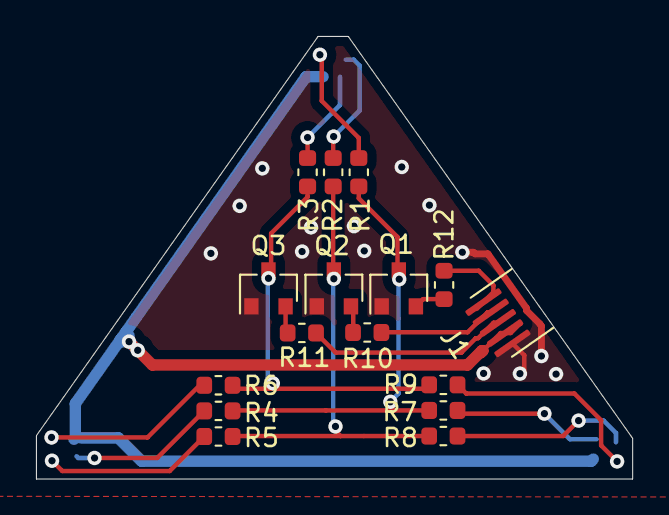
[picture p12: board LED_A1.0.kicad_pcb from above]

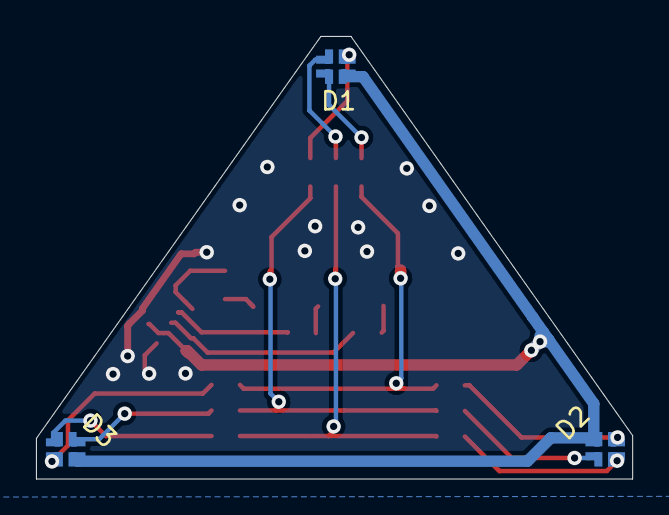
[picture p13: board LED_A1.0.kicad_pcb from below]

Board: 2 copper layers, 33.1 x 24.6 mm, 19 parts (3 on the bottom side), 20 nets.

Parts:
D1, D2, D3: LED_ARGB; RGD-compatible
J1: Conn_01x05; FPC-0.7x5-Handsoldering
Q1, Q2, Q3: S8050; SOT-23
R1, R2, R3, R4, R5, R6, R7, R8, R9: 10K; R_0603_1608Metric
R10, R11, R12: 1K; R_0603_1608Metric

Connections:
+5V: D1.1, D2.1, D3.1, J1.2
/LED_B: J1.5, R12.2
/LED_B_O: Q1.3, R1.1, R4.1, R7.1
/LED_G: J1.3, R11.2
/LED_G_O: Q3.3, R3.1, R6.1, R9.1
/LED_R: J1.4, R10.2
/LED_R_O: Q2.3, R2.1, R5.1, R8.1
Earth: J1.1, Q1.1, Q2.1, Q3.1
unnamed: D1.2, R3.2
unnamed: D1.3, R2.2
unnamed: D1.4, R1.2
unnamed: D2.2, R6.2
unnamed: D2.3, R5.2
unnamed: D2.4, R4.2
unnamed: D3.2, R9.2
unnamed: D3.3, R8.2
unnamed: D3.4, R7.2
unnamed: Q1.2, R12.1
unnamed: Q2.2, R10.1
unnamed: Q3.2, R11.1

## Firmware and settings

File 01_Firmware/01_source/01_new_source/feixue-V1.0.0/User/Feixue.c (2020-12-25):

/**
 * FeixueMask Firmware
 * Copyright (c) 2020 LonlyPan. All rights reserved.
 *
 *
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
 */

/**
  * @file:    Feixue.c
  * @author:  LonlyPan
  * @version: V0.1
  * @date:    2020-12-10
  * @brief:   初始化外设
  *           LVGL初始化
  *			  LVGL-screen界面制作
  *    		   任务处理
  * @attention:
  *
  * @History:
  *    1.Version: V0.1
  *         date: 2020-12-10
  *        notes: 初始版本
  *       author: LonlyPan
  */

/* Define to prevent recursive inclusion -------------------------------------*/
#include "feixue.h"
#include "spi.h"
#include "lcd.h"
#include "tim.h"
#include "lvgl.h"
#include "lv_port_disp.h"
#include "lv_style.h"
#include "timer.h"
#include "stdio.h"
#include "speech_usart.h"

/**
 * @brief  sine 函数，泰勒公式
 * @note   参考：https://stackoverflow.com/questions/23876260/source-code-for-trigonometric-functions-calculations
 * @param  x 当前角度值(0~360)，角度顺时针递增
 * @retval 由x角度计算的正弦值（0~1）
 */
double sine_taylor(double x)
{
	/* 将角度限定在 -90~90 度内，用于后续计算 */
	if(x>90 && x <= 180)
		x = 180 - x;
    else if(x>180 && x <= 270)
		x = 180 - x;
	else if(x>270 && x <= 360)
		x = x - 360;

	/* 将角度值转换为 -PI/2~PI/2 之间 */
    x = x * 2*3.14 / 360.0;
    // useful to pre-calculate
    double x2 = x*x;
    double x4 = x2*x2;

    //计算条件
    //只要abs(x) < sqrt(6)（即2.45），所有项都是正数。
    //为了准确起见，无论如何都应将上述范围之外的值减小为[-pi / 2，pi / 2]。
    //必须注意阶乘。
    //它们可以由编译器预先计算，但是较高的值将超过int的存储容量。
    //因此，强制编译器使用无符号的long long（如果有）或doubles类型。
    double t1 = x * (1.0 - x2 / (2*3));
    double x5 = x * x4;
    double t2 = x5 * (1.0 - x2 / (6*7)) / (1.0* 2*3*4*5);
    double x9 = x5 * x4;
    double t3 = x9 * (1.0 - x2 / (10*11)) / (1.0* 2*3*4*5*6*7*8*9);
    double x13 = x9 * x4;
    double t4 = x13 * (1.0 - x2 / (14*15)) / (1.0* 2*3*4*5*6*7*8*9*10*11*12*13);
    //如果您对准确性由更高要求，请添加更多内容。
    //但是请记住，x小于2，但阶乘增长非常快，所以我怀疑2 ^ 17/17 作用微乎其微（再添加一行计算就会是计算 2^17 阶乘）。
    //甚至与t1相比，t4可能已经太小而无所谓。

    // Sum backwards
    double result = t4;
    result += t3;
    result += t2;
    result += t1;

    return result;
}

/**
 * @brief  cosine 函数，泰勒公式
 * @note   参考：https://stackoverflow.com/questions/23876260/source-code-for-trigonometric-functions-calculations
 * @param  x 当前角度值(0~360)，角度顺时针递增
 * @retval 由x角度计算的余弦值（0~1）
 */
double cose_taylor(double x)
{

    const float Q = 90; // pi/2
    const float BASE_PI =180;
    x += Q;

    if(x > BASE_PI)
        x -= 2 * BASE_PI;

    return( sine_taylor(x));
}

static lv_style_t arc_block_style;  /* 大圆弧块的样式 */
static lv_style_t arc_line_style;   /* 小圆弧块的样式 */


lv_obj_t * big_arc; /* 大的弧块 */
lv_obj_t * tiny_arc;/* 小的弧块 */
lv_obj_t * out_arc; /* 外弧线 */
lv_obj_t * in_arc1; /* 内弧线1 */
lv_obj_t * in_arc2; /* 内弧线1 */

/* 内外弧之间的短线 */
lv_obj_t * line1;
lv_obj_t * line2;
lv_obj_t * line3;
lv_obj_t * line4;

static u8 current_screen = 0;

/* 短线1端点值 */
static lv_point_t line_points1[2] = {{0,0},{0,0}};
/* 短线1与水平夹角，逆时针递增 */
static int line_angle= 87;
/* 短线2 */
static lv_point_t line_points2[2] = {{0,0},{0,0}};
static int line2_angle_offest = 51;
/* 短线3 */
static lv_point_t line_points3[2] = {{0,0},{0,0}};
static int line3_angle_offest = 80;
/* 短线4 */
static lv_point_t line_points4[2] = {{0,0},{0,0}};
static int line4_angle_offest = -33;

static int16_t big_arc_block_start_angle = 330;  /* 大圆弧块一个端边对应角度 */
static int16_t big_arc_block_offer = 300;        /* 大圆弧块的圆心角 */

static int16_t tiny_arc_block_start_angle = 125;
static int16_t tiny_arc_block_end_angle = 25;

static int16_t out_arc_block_start_angle = 285;
static int16_t out_arc_block_off = 265;

static int16_t in_arc1_block_start_angle = 305;
static int16_t in_arc1_block_offer = 110;

static int16_t in_arc2_block_start_angle = 220;
static int16_t in_arc2_block_offer = 55;



#define MAIN_COLOR lv_color_make(255, 213,0)   /* 界面的主色 猩造黄*/
/**
 * An `lv_task` to call periodically to set the angles of the arc
 * @param t
 */
static uint32_t arc_size_reduce = 0;  /* 圆弧的缩小半径 ，动画后期部分圆弧会缩小，当前半径 = 初始值 -arc_size_reduce */


lv_obj_t *show_scr1;  /* 显示界面1：动画*/
lv_obj_t *show_scr2;  /* 显示界面2：圆环*/
lv_obj_t *show_scr3;  /* 显示界面3：圆环+浅色实心圆*/
lv_obj_t *show_scr4;  /* 显示界面4：浅色实心圆*/

lv_obj_t *scr1_label; /* 通用字符标签，主要用于测试 */

lv_task_t * scr1_task;/* 定期调用“ lv_task”以设置圆弧的角度 */
static bool scr1_task_flag = true; /* scr1_task 运行标识符，目前并未在 LVGL 中找到暂停 task 的函数，只有删除函数，但删除后就无法再调用以实现我们想要的重复显示 */

millis_t run_times; /* 系统运行时间 ms */
void screen_change(u8 addr);  /* 切换界面 */

/**
 * @brief  复位界面1的各图案
 * @note   动画期间会改变各图案的角度值、大小等，需再重新运行界面1前初始化
 * @param
 * @retval
 */
static void rest_show_scr1()
{
	/* 透明度 */
    lv_obj_set_style_local_line_opa(big_arc,LV_ARC_PART_INDIC,LV_STATE_DEFAULT,255);
    lv_obj_set_style_local_line_opa(tiny_arc,LV_ARC_PART_INDIC,LV_STATE_DEFAULT,255);
    lv_obj_set_style_local_line_opa(in_arc1,LV_ARC_PART_INDIC,LV_STATE_DEFAULT,255);
    lv_obj_set_style_local_line_opa(in_arc2,LV_ARC_PART_INDIC,LV_STATE_DEFAULT,255);
    lv_obj_set_style_local_line_opa(out_arc,LV_ARC_PART_INDIC,LV_STATE_DEFAULT,255);

    /* 线宽度 */
    lv_style_set_line_width(&arc_line_style, LV_STATE_DEFAULT,7);
    lv_obj_set_style_local_line_width(in_arc1, LV_ARC_PART_INDIC,LV_STATE_DEFAULT,7);

    /* 角度 */
    lv_arc_set_angles(big_arc,big_arc_block_start_angle,big_arc_block_start_angle-big_arc_block_offer);
    lv_arc_set_angles(tiny_arc, tiny_arc_block_start_angle,150);
    lv_arc_set_angles(in_arc1, in_arc1_block_start_angle,in_arc1_block_start_angle-in_arc1_block_offer);
    lv_arc_set_angles(in_arc2, in_arc2_block_start_angle,in_arc2_block_start_angle+in_arc2_block_offer);
    lv_arc_set_angles(out_arc, out_arc_block_start_angle-out_arc_block_off,out_arc_block_start_angle);

    /* 大小 */
    lv_obj_set_size(in_arc1, 174, 174);
    lv_obj_set_size(in_arc2, 174, 174);
    lv_obj_set_size(tiny_arc, 240, 240);
    //lv_obj_set_size(in_arc2, 240, 240);

    /* 对齐 */
    lv_obj_align(in_arc1, show_scr1, LV_ALIGN_CENTER, 0, 0);
    lv_obj_align(in_arc2, show_scr1, LV_ALIGN_CENTER, 0, 0);
    lv_obj_align(tiny_arc, show_scr1, LV_ALIGN_CENTER, 0, 0);

    /* 各短线段 */
    line_points1[0].x= (int)(120+80*cose_taylor(line_angle));
    line_points1[0].y =(int)(120-80*sine_taylor(line_angle));
    line_points1[1].x= (int)(120+116*cose_taylor(line_angle));
    line_points1[1].y = (int)(120-116*sine_taylor(line_angle));


    line_points2[0].x= (int)(120+80*cose_taylor(line_angle+line2_angle_offest));
    line_points2[0].y =(int)(120-80*sine_taylor(line_angle+line2_angle_offest));
    line_points2[1].x= (int)(120+116*cose_taylor(line_angle+line2_angle_offest));
    line_points2[1].y = (int)(120-116*sine_taylor(line_angle+line2_angle_offest));


    line_points3[0].x= (int)(120+80*cose_taylor(line_angle+line3_angle_offest));
    line_points3[0].y =(int)(120-80*sine_taylor(line_angle+line3_angle_offest));
    line_points3[1].x= (int)(120+116*cose_taylor(line_angle+line3_angle_offest));
    line_points3[1].y = (int)(120-116*sine_taylor(line_angle+line3_angle_offest));


    line_points4[0].x= (int)(120+80*cose_taylor(line_angle+line4_angle_offest));
    line_points4[0].y =(int)(120-80*sine_taylor(line_angle+line4_angle_offest));
    line_points4[1].x= (int)(120+116*cose_taylor(line_angle+line4_angle_offest));
    line_points4[1].y = (int)(120-116*sine_taylor(line_angle+line4_angle_offest));

    lv_obj_set_style_local_line_opa(line1,LV_LINE_PART_MAIN,LV_STATE_DEFAULT,255);
    lv_obj_set_style_local_line_opa(line2,LV_LINE_PART_MAIN,LV_STATE_DEFAULT,255);
    lv_obj_set_style_local_line_opa(line3,LV_LINE_PART_MAIN,LV_STATE_DEFAULT,255);
    lv_obj_set_style_local_line_opa(line4,LV_LINE_PART_MAIN,LV_STATE_DEFAULT,255);

    lv_line_set_points(line2, line_points2,2);
    lv_line_set_points(line1, line_points1,2);
    lv_line_set_points(line3, line_points3,2);
    lv_line_set_points(line4, line_points4,2);


}
/**
 * @brief   定期调用 “show_scr1_loader” 以设置圆弧的角度
 * @note    动画期间会改变各图案的角度值、大小等，需再重新运行界面1前初始化
 * @param   lv_task_t 自定义任务传参，此处并未用到
 * @retval
 */
static void show_scr1_loader(lv_task_t * t)
{

	/* 以下字符显示语句（原本用于测试使用）不可删除，会导致语音切换屏幕不工作，原因未知*/
	/* 这里改为显示 空字符，不显示任何字符 */
	char buf[30]; /* 储存转换后的字符 字符标签不支持变量直接显示，需要先将变量进行转换 */
    sprintf(buf, "%d", fps_cnt);//将data转换为fmt样式的字符
    lv_label_set_text(scr1_label," ");

	if(scr1_task_flag ){

        big_arc_block_start_angle -= 3;  /* 角度变化量，同时该值也是旋转角度变化的基准值  */
        tiny_arc_block_start_angle -= 3; /* 角度变化量 */
        in_arc1_block_start_angle -= 3;  /* 角度变化量 */
        in_arc2_block_start_angle -= 3;  /* 角度变化量 */
        line_angle += 3;  /* 角度变化量 */

        /* 重新设定各圆弧、线段位置 */
        lv_arc_set_angles(big_arc, big_arc_block_start_angle,(big_arc_block_start_angle < big_arc_block_offer)? big_arc_block_start_angle+60:big_arc_block_start_angle - big_arc_block_offer);
        lv_arc_set_angles(tiny_arc, tiny_arc_block_start_angle < 0 ? (360+tiny_arc_block_start_angle):tiny_arc_block_start_angle ,tiny_arc_block_start_angle+tiny_arc_block_end_angle);
        if(big_arc_block_start_angle > 200) {  /* 当角度变化到该值后，内部圆弧不再旋转 */
                lv_arc_set_angles(in_arc1, in_arc1_block_start_angle,in_arc1_block_start_angle-in_arc1_block_offer);
                lv_arc_set_angles(in_arc2, in_arc2_block_start_angle,in_arc2_block_start_angle+in_arc2_block_offer);
        }

        line_points1[0].x= (int)(120+80*cose_taylor(line_angle));
        line_points1[0].y =(int)(120-80*sine_taylor(line_angle));
        line_points1[1].x= (int)(120+116*cose_taylor(line_angle));
        line_points1[1].y = (int)(120-116*sine_taylor(line_angle));


        line_points2[0].x= (int)(120+80*cose_taylor(line_angle+line2_angle_offest));
        line_points2[0].y =(int)(120-80*sine_taylor(line_angle+line2_angle_offest));
        line_points2[1].x= (int)(120+116*cose_taylor(line_angle+line2_angle_offest));
        line_points2[1].y = (int)(120-116*sine_taylor(line_angle+line2_angle_offest));


        line_points3[0].x= (int)(120+80*cose_taylor(line_angle+line3_angle_offest));
        line_points3[0].y =(int)(120-80*sine_taylor(line_angle+line3_angle_offest));
        line_points3[1].x= (int)(120+116*cose_taylor(line_angle+line3_angle_offest));
        line_points3[1].y = (int)(120-116*sine_taylor(line_angle+line3_angle_offest));


        line_points4[0].x= (int)(120+80*cose_taylor(line_angle+line4_angle_offest));
        line_points4[0].y =(int)(120-80*sine_taylor(line_angle+line4_angle_offest));
        line_points4[1].x= (int)(120+116*cose_taylor(line_angle+line4_angle_offest));
        line_points4[1].y = (int)(120-116*sine_taylor(line_angle+line4_angle_offest));


        lv_line_set_points(line2, line_points2,2);
        lv_line_set_points(line1, line_points1,2);
        lv_line_set_points(line3, line_points3,2);
        lv_line_set_points(line4, line_points4,2);

        /* 手绘动画 一帧对应角度变化量约为3度 */
        /* 程序的顺序与实际显示顺序相反，所以最后一行 else if 是动画最先部分 */
        if(big_arc_block_start_angle <= 145) {  /* 界面1 动画停止，显示结束 */
            lv_arc_set_angles(in_arc1,0,0);
            line_angle= 87;
            big_arc_block_start_angle = 330;
            tiny_arc_block_start_angle = 125;
            out_arc_block_start_angle = 285;
            in_arc1_block_start_angle = 305;
            in_arc2_block_start_angle = 220;
            //lv_arc_set_angles(in_arc1,0,0);
            scr1_task_flag = false;

			current_screen = 2;                /* 切换到界面2 */
			screen_change(current_screen);
        }

        else if(big_arc_block_start_angle <= 155) { /* 内弧线收缩为点，同时改变线宽（否则 点 会很大） */

            arc_size_reduce = 169;
            lv_arc_set_angles(in_arc1,0,359);
            lv_obj_set_style_local_line_width(in_arc1, LV_ARC_PART_INDIC,LV_STATE_DEFAULT,4);
            lv_obj_set_size(in_arc1, 174-arc_size_reduce, 174-arc_size_reduce);
            lv_obj_align(in_arc1, NULL, LV_ALIGN_CENTER, 0, 0);

        }

        else if(big_arc_block_start_angle <= 165) { /* 外弧线消失，内弧线缩短并收缩 、变暗*/

            arc_size_reduce = 150;
            lv_arc_set_start_angle(in_arc1,in_arc1_block_start_angle+110);
            lv_obj_set_size(in_arc1, 174-arc_size_reduce, 174-arc_size_reduce);
            lv_obj_set_style_local_line_opa(in_arc1,LV_ARC_PART_INDIC,LV_STATE_DEFAULT,80);
            lv_obj_align(in_arc1, NULL, LV_ALIGN_CENTER, 0, 0);

        }
        else if(big_arc_block_start_angle <= 175) {  /* 外弧线消失，内弧线收缩并缩短 */
            lv_arc_set_angles(out_arc,0,0);

            arc_size_reduce = 130;

            lv_arc_set_start_angle(in_arc1,in_arc1_block_start_angle+80);
            lv_obj_set_size(in_arc1, 174-arc_size_reduce, 174-arc_size_reduce);
            lv_obj_set_style_local_line_opa(in_arc1,LV_ARC_PART_INDIC,LV_STATE_DEFAULT,150);

            lv_obj_align(in_arc1, NULL, LV_ALIGN_CENTER, 0, 0);

        }
        else if(big_arc_block_start_angle <= 180) { /* 外弧线缩短，内弧线收缩 */
            lv_arc_set_end_angle(out_arc,40);

            arc_size_reduce = 90;

            lv_obj_set_size(in_arc1, 174-arc_size_reduce, 174-arc_size_reduce);
            lv_obj_align(in_arc1, NULL, LV_ALIGN_CENTER, 0, 0);
        }

        else if(big_arc_block_start_angle <= 190) {/* 小圆弧块消失，外弧线缩短，内弧线收缩 */
            lv_obj_set_style_local_line_opa(tiny_arc,LV_ARC_PART_INDIC,LV_STATE_DEFAULT,0);
            lv_arc_set_end_angle(out_arc,out_arc_block_start_angle-195);
            lv_arc_set_angles(in_arc2, 0,0);

            arc_size_reduce = 60;
            lv_obj_set_size(in_arc1, 174-arc_size_reduce, 174-arc_size_reduce);
            lv_obj_align(in_arc1, NULL, LV_ALIGN_CENTER, 0, 0);
            lv_obj_align(tiny_arc, NULL, LV_ALIGN_CENTER, 0, 0);
        }

        else if(big_arc_block_start_angle <= 195) {/* 小圆弧块变暗，外弧线、内弧线2缩短，小圆弧块、内弧线收缩 */
            lv_obj_set_style_local_line_opa(tiny_arc,LV_ARC_PART_INDIC,LV_STATE_DEFAULT,30);
            lv_arc_set_end_angle(out_arc,out_arc_block_start_angle-135);
            lv_arc_set_start_angle(in_arc2,in_arc2_block_start_angle+in_arc2_block_offer-20);

            arc_size_reduce = 30;
            lv_obj_set_size(in_arc1, 174-arc_size_reduce, 174-arc_size_reduce);
            lv_obj_set_size(in_arc2, 174-arc_size_reduce, 174-arc_size_reduce);
            lv_obj_set_size(tiny_arc, 240-arc_size_reduce, 240-arc_size_reduce);
            lv_obj_align(in_arc1, NULL, LV_ALIGN_CENTER, 0, 0);
            lv_obj_align(in_arc2, NULL, LV_ALIGN_CENTER, 0, 0);
            lv_obj_align(tiny_arc, NULL, LV_ALIGN_CENTER, 0, 0);
        }
        else if(big_arc_block_start_angle <= 200) {/* 小圆弧块变暗，外弧线缩短，小圆弧块、内弧线收缩 */
            lv_obj_set_style_local_line_opa(tiny_arc,LV_ARC_PART_INDIC,LV_STATE_DEFAULT,100);
            lv_arc_set_end_angle(out_arc,out_arc_block_start_angle-95);
            arc_size_reduce = 10;
            lv_obj_set_size(in_arc1, 174-arc_size_reduce, 174-arc_size_reduce);
            lv_obj_set_size(in_arc2, 174-arc_size_reduce, 174-arc_size_reduce);
            lv_obj_set_size(tiny_arc, 240-arc_size_reduce, 240-arc_size_reduce);
            lv_obj_align(in_arc1, NULL, LV_ALIGN_CENTER, 0, 0);
            lv_obj_align(in_arc2, NULL, LV_ALIGN_CENTER, 0, 0);
            lv_obj_align(tiny_arc, NULL, LV_ALIGN_CENTER, 0, 0);
        }
        else if(big_arc_block_start_angle <= 203) {/* 外弧线缩短*/
            lv_arc_set_end_angle(out_arc,out_arc_block_start_angle-60);

        }
        else if(big_arc_block_start_angle <= 206) {/* 小圆弧块恢复，线段4消失 ，外弧线缩短*/
            lv_obj_set_style_local_line_opa(tiny_arc,LV_ARC_PART_INDIC,LV_STATE_DEFAULT,255);
            lv_obj_set_style_local_line_opa(line4,LV_LINE_PART_MAIN,LV_STATE_DEFAULT,0);
            lv_arc_set_end_angle(out_arc,out_arc_block_start_angle-35);

        }
        else if(big_arc_block_start_angle <= 209) {/* 小圆弧块变暗，线段4变暗 ，外弧线缩短*/
            lv_obj_set_style_local_line_opa(tiny_arc,LV_ARC_PART_INDIC,LV_STATE_DEFAULT,50);
            lv_obj_set_style_local_line_opa(line4,LV_LINE_PART_MAIN,LV_STATE_DEFAULT,50);
            lv_arc_set_end_angle(out_arc,out_arc_block_start_angle-15);
        }
        else if(big_arc_block_start_angle <= 214) {/* 小圆弧块变暗，线段4变暗 ，外弧线缩短*/
            lv_obj_set_style_local_line_opa(tiny_arc,LV_ARC_PART_INDIC,LV_STATE_DEFAULT,240);
            lv_obj_set_style_local_line_opa(line4,LV_LINE_PART_MAIN,LV_STATE_DEFAULT,150);
            lv_arc_set_end_angle(out_arc,out_arc_block_start_angle-5);
        }
        else if(big_arc_block_start_angle <= 360 -138) {/* 大圆弧块消失，线段2消失 */
            lv_obj_set_style_local_line_opa(big_arc,LV_ARC_PART_INDIC,LV_STATE_DEFAULT,0);
            lv_obj_set_style_local_line_opa(line2,LV_LINE_PART_MAIN,LV_STATE_DEFAULT,0);
        }
        else if(big_arc_block_start_angle <= 360 -135) {/* 大圆弧块变暗，线段2变暗、4恢复 */
            lv_obj_set_style_local_line_opa(big_arc,LV_ARC_PART_INDIC,LV_STATE_DEFAULT,200);
            lv_obj_set_style_local_line_opa(line4,LV_LINE_PART_MAIN,LV_STATE_DEFAULT,255);
            lv_obj_set_style_local_line_opa(line2,LV_LINE_PART_MAIN,LV_STATE_DEFAULT,150);
        }
        else if(big_arc_block_start_angle <= 360 -132) {/* 大圆弧块恢复，线段2恢复、4消失  */
            lv_obj_set_style_local_line_opa(big_arc,LV_ARC_PART_INDIC,LV_STATE_DEFAULT,255);
            lv_obj_set_style_local_line_opa(line4,LV_LINE_PART_MAIN,LV_STATE_DEFAULT,0);
            lv_obj_set_style_local_line_opa(line2,LV_LINE_PART_MAIN,LV_STATE_DEFAULT,255);
        }
        else if(big_arc_block_start_angle <= 360 -128) {/* 大圆弧块变暗，线段1、2 消失 */
            lv_obj_set_style_local_line_opa(big_arc,LV_ARC_PART_INDIC,LV_STATE_DEFAULT,120);
            lv_obj_set_style_local_line_opa(line1,LV_LINE_PART_MAIN,LV_STATE_DEFAULT,0);
            lv_obj_set_style_local_line_opa(line2,LV_LINE_PART_MAIN,LV_STATE_DEFAULT,0);
        }
        else if(big_arc_block_start_angle <= 360 -125) {/* 大圆弧块变暗，线段1、2 变暗 */
            lv_obj_set_style_local_line_opa(big_arc,LV_ARC_PART_INDIC,LV_STATE_DEFAULT,200);
            lv_obj_set_style_local_line_opa(line1,LV_LINE_PART_MAIN,LV_STATE_DEFAULT,150);
            lv_obj_set_style_local_line_opa(line2,LV_LINE_PART_MAIN,LV_STATE_DEFAULT,150);
        }
        else if(big_arc_block_start_angle <= 360 -123) { /* 线段1 恢复 */
            lv_obj_set_style_local_line_opa(line1,LV_LINE_PART_MAIN,LV_STATE_DEFAULT,255);
        }
        else if(big_arc_block_start_angle <= 360 -118) { /* 线段1 消失 线段3 消失 */
            lv_obj_set_style_local_line_opa(line1,LV_LINE_PART_MAIN,LV_STATE_DEFAULT,0);
             lv_obj_set_style_local_line_opa(line3,LV_LINE_PART_MAIN,LV_STATE_DEFAULT,0);
        }
        else if(big_arc_block_start_angle <= 360 -115) { /* 线段1 变暗 线段3 变亮 */
            lv_obj_set_style_local_line_opa(line1,LV_LINE_PART_MAIN,LV_STATE_DEFAULT,150);
            lv_obj_set_style_local_line_opa(line3,LV_LINE_PART_MAIN,LV_STATE_DEFAULT,150);
        }
        else if(big_arc_block_start_angle <= 360 -110) { /* 线段3 消失 */
            lv_obj_set_style_local_line_opa(line3,LV_LINE_PART_MAIN,LV_STATE_DEFAULT,0);
        }
        else if(big_arc_block_start_angle <= 360 -102) { /* 线段3 变暗 */
            lv_obj_set_style_local_line_opa(line3,LV_LINE_PART_MAIN,LV_STATE_DEFAULT,150);
        }
	}
}
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
void loop()
{
	speech_process();

	if(ELAPSED(millis(), run_times)){ /* 每12秒唤醒一次语音芯片。芯片原生每15秒会休眠，之后需要先说唤醒词唤醒，才能说指令，这里为了简单，保持唤醒状态 */
		run_times = millis()+13000;
		speeech_wake_up();
	}
	lv_task_handler();

}

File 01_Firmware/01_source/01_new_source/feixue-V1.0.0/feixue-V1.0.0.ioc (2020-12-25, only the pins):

Mcu.UserName=STM32F401CCUx
PA10.Signal=USART1_RX
PA13.Signal=SYS_JTMS-SWDIO
PA14.Signal=SYS_JTCK-SWCLK
PA3.GPIO_Label=BLK
PA3.Signal=GPIO_Output
PA4.GPIO_Label=DC
PA4.Signal=GPIO_Output
PA5.Signal=SPI1_SCK
PA7.Signal=SPI1_MOSI
PA9.Signal=USART1_TX
PB0.GPIO_Label=RES
PB0.Signal=GPIO_Output
PB13.GPIO_Label=LED_G
PB13.Signal=GPIO_Output
PB14.GPIO_Label=LED_R
PB14.Signal=GPIO_Output
PB15.GPIO_Label=LED_B
PB15.Signal=GPIO_Output

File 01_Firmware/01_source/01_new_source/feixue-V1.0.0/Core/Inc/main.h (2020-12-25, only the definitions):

#define BLK_Pin GPIO_PIN_3
#define BLK_GPIO_Port GPIOA
#define DC_Pin GPIO_PIN_4
#define DC_GPIO_Port GPIOA
#define RES_Pin GPIO_PIN_0
#define RES_GPIO_Port GPIOB
#define LED_G_Pin GPIO_PIN_13
#define LED_G_GPIO_Port GPIOB
#define LED_R_Pin GPIO_PIN_14
#define LED_R_GPIO_Port GPIOB
#define LED_B_Pin GPIO_PIN_15
#define LED_B_GPIO_Port GPIOB

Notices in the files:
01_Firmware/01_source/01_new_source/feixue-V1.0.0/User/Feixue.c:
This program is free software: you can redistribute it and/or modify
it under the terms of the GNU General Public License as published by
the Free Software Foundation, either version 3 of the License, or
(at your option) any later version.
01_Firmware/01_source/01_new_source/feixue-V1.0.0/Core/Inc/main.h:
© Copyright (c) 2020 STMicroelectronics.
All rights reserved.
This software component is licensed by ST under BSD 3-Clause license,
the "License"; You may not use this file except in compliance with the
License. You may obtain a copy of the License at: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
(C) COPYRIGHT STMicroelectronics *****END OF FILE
